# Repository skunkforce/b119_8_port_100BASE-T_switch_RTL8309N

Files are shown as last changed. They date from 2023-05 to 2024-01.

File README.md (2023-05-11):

# edgy_board number b119
This design is part of the [edgy board project](https://github.com/skunkforce/edgy_boards). It provides a cheap 8-port 100BASE-T switch.

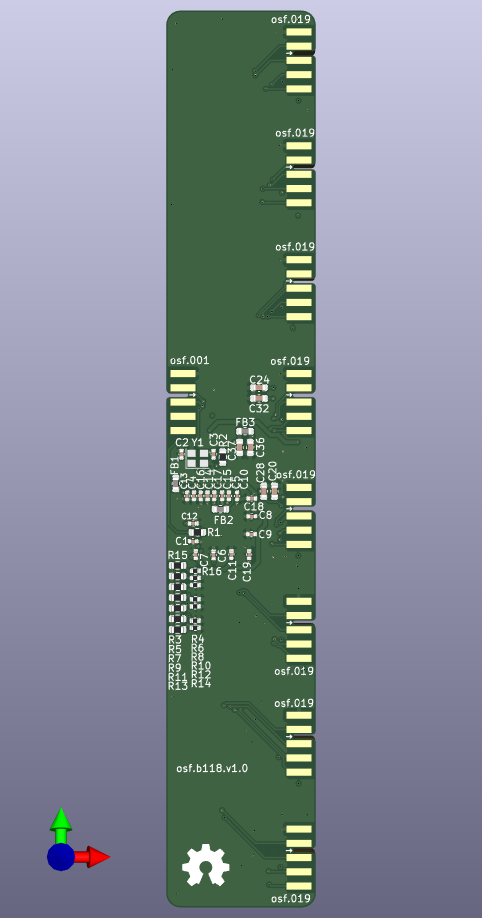
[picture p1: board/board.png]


# getting started
This repository uses submodules. After cloning use the command 

```$ git submodule update --init --recursive```

to pull the submodules before opening the project with kicad. 

# Tests
Tests can be found in [TESTS.md](TESTS.md)

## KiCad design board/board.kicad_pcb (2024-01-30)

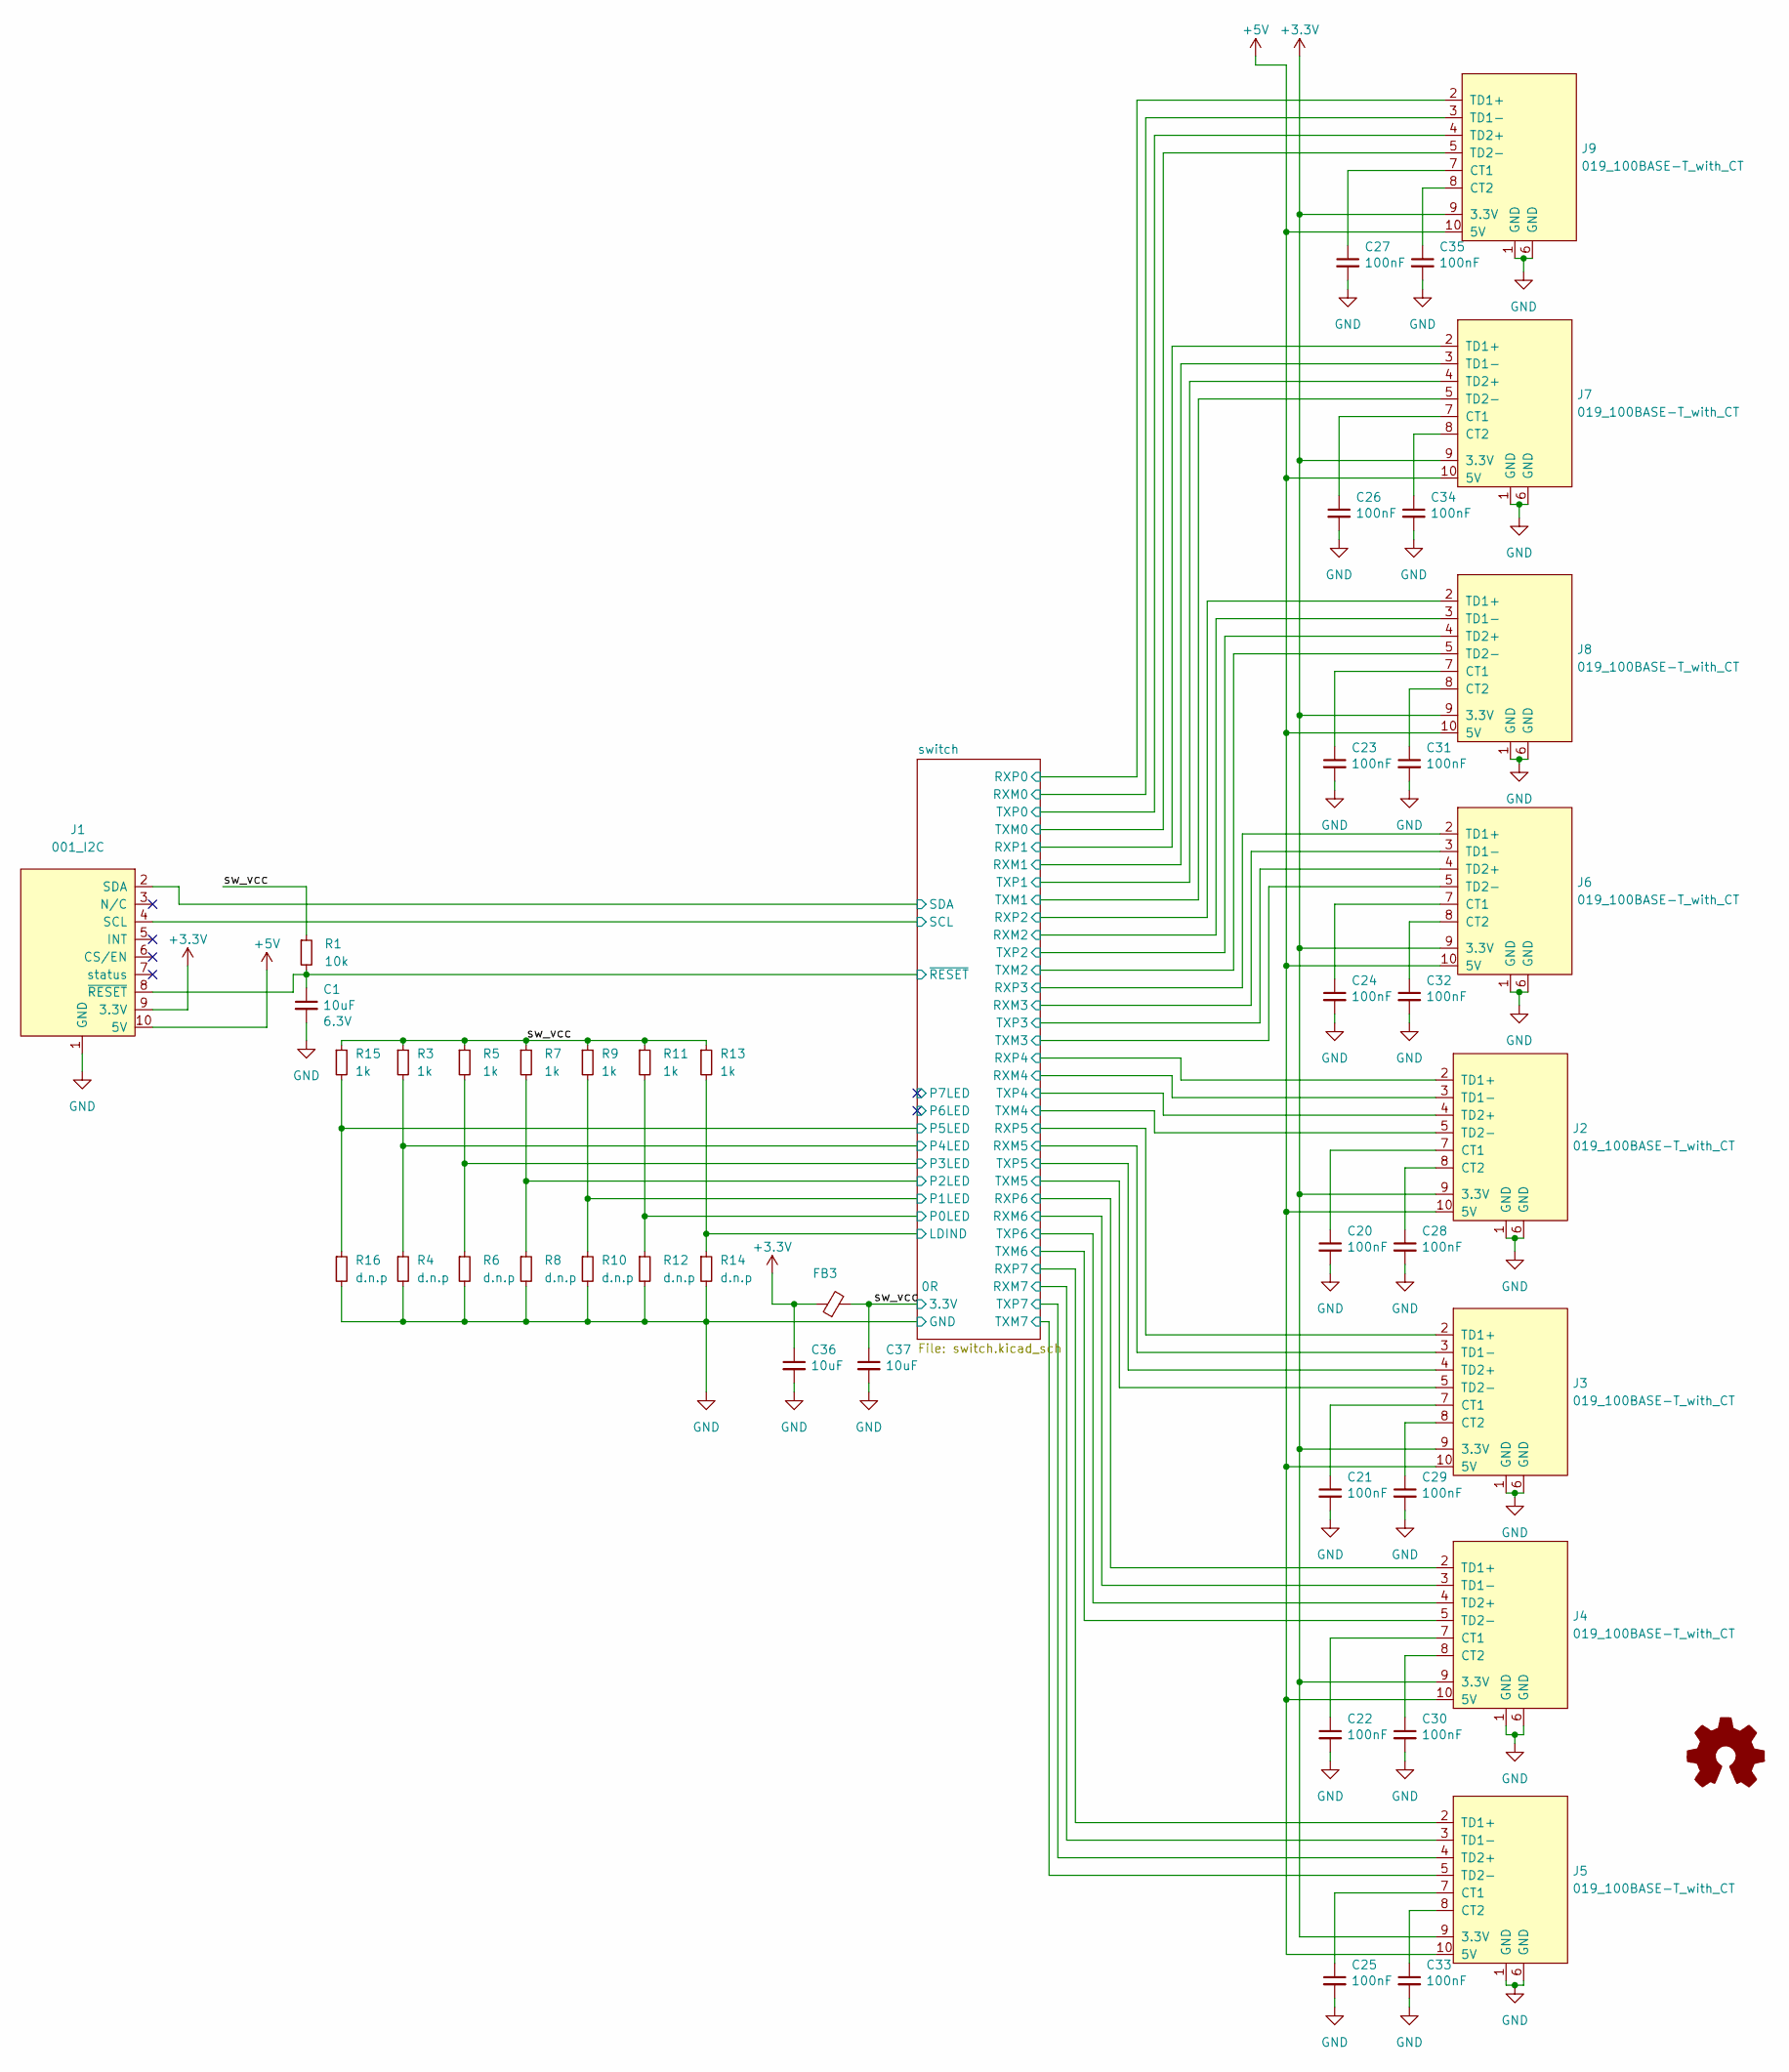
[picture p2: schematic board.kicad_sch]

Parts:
C1: 10uF; C_0402_1005Metric; Voltage 6.3V; MPN CL05A105MP5NNNC; Digi-Key_PN 1276-1448-1-ND
C20, C21, C22, C23, C24, C25, C26, C27, C28, C29, C30, C31, C32, C33, C34, C35: 100nF; C_0603_1608Metric; lcsc C14663
C36, C37: 10uF; C_0402_1005Metric; lcsc C15525
FB3: 0R; L_0603_1608Metric; MPN 74279228111; lcsc C21189
J1: 001_I2C; on_edge_2x05_device
J2, J3, J4, J5, J6, J7, J8, J9: 019_100BASE-T_with_CT; on_edge_2x05_host
LOGO1: Logo_Open_Hardware_Small; OSHW-Symbol_6.7x6mm_SilkScreen
R1: 10k; R_0402_1005Metric; lcsc C25744
R3, R5, R7, R9, R11, R13, R15: 1k; R_0402_1005Metric; lcsc C11702
R4, R6, R8, R10, R12, R14, R16: d.n.p; R_0402_1005Metric

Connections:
+3.3V: C36.1, FB3.1, J1.9 (3.3V), J2.9 (3.3V), J3.9 (3.3V), J4.9 (3.3V), J5.9 (3.3V), J6.9 (3.3V), J7.9 (3.3V), J8.9 (3.3V), J9.9 (3.3V)
+5V: J1.10 (5V), J2.10 (5V), J3.10 (5V), J4.10 (5V), J5.10 (5V), J6.10 (5V), J7.10 (5V), J8.10 (5V), J9.10 (5V)
/sw_vcc: C37.1, FB3.2, R1.1, R3.1, R5.1, R7.1, R9.1, R11.1, R13.1, R15.1; also elsewhere on the board
/switch/LDIND: R13.2, R14.1; also elsewhere on the board
/switch/P0LED: R11.2, R12.1; also elsewhere on the board
/switch/P1LED: R9.2, R10.1; also elsewhere on the board
/switch/P2LED: R7.2, R8.1; also elsewhere on the board
/switch/P3LED: R5.2, R6.1; also elsewhere on the board
/switch/P4LED: R3.2, R4.1; also elsewhere on the board
/switch/P5LED: R15.2, R16.1; also elsewhere on the board
/switch/RXM0: J9.3 (TD1-); also elsewhere on the board
/switch/RXM1: J7.3 (TD1-); also elsewhere on the board
/switch/RXM2: J8.3 (TD1-); also elsewhere on the board
/switch/RXM3: J6.3 (TD1-); also elsewhere on the board
/switch/RXM4: J2.3 (TD1-); also elsewhere on the board
/switch/RXM5: J3.3 (TD1-); also elsewhere on the board
/switch/RXM6: J4.3 (TD1-); also elsewhere on the board
/switch/RXM7: J5.3 (TD1-); also elsewhere on the board
/switch/RXP0: J9.2 (TD1+); also elsewhere on the board
/switch/RXP1: J7.2 (TD1+); also elsewhere on the board
/switch/RXP2: J8.2 (TD1+); also elsewhere on the board
/switch/RXP3: J6.2 (TD1+); also elsewhere on the board
/switch/RXP4: J2.2 (TD1+); also elsewhere on the board
/switch/RXP5: J3.2 (TD1+); also elsewhere on the board
/switch/RXP6: J4.2 (TD1+); also elsewhere on the board
/switch/RXP7: J5.2 (TD1+); also elsewhere on the board
/switch/SCL: J1.4 (SCL); also elsewhere on the board
/switch/SDA: J1.2 (SDA); also elsewhere on the board
/switch/TXM0: J9.5 (TD2-); also elsewhere on the board
/switch/TXM1: J7.5 (TD2-); also elsewhere on the board
/switch/TXM2: J8.5 (TD2-); also elsewhere on the board
/switch/TXM3: J6.5 (TD2-); also elsewhere on the board
/switch/TXM4: J2.5 (TD2-); also elsewhere on the board
/switch/TXM5: J3.5 (TD2-); also elsewhere on the board
/switch/TXM6: J4.5 (TD2-); also elsewhere on the board
/switch/TXM7: J5.5 (TD2-); also elsewhere on the board
/switch/TXP0: J9.4 (TD2+); also elsewhere on the board
/switch/TXP1: J7.4 (TD2+); also elsewhere on the board
/switch/TXP2: J8.4 (TD2+); also elsewhere on the board
/switch/TXP3: J6.4 (TD2+); also elsewhere on the board
/switch/TXP4: J2.4 (TD2+); also elsewhere on the board
/switch/TXP5: J3.4 (TD2+); also elsewhere on the board
/switch/TXP6: J4.4 (TD2+); also elsewhere on the board
/switch/TXP7: J5.4 (TD2+); also elsewhere on the board
/switch/~RESET: C1.1, J1.8 (~RESET), R1.2; also elsewhere on the board
GND: C1.2, C20.2, C21.2, C22.2, C23.2, C24.2, C25.2, C26.2, C27.2, C28.2, C29.2, C30.2, C31.2, C32.2, C33.2, C34.2, C35.2, C36.2, C37.2, J1.1 (GND), J2.1 (GND), J2.6 (GND), J3.1 (GND), J3.6 (GND), J4.1 (GND), J4.6 (GND), J5.1 (GND), J5.6 (GND), J6.1 (GND), J6.6 (GND), J7.1 (GND), J7.6 (GND), J8.1 (GND), J8.6 (GND), J9.1 (GND), J9.6 (GND), R4.2, R6.2, R8.2, R10.2, R12.2, R14.2, R16.2; also elsewhere on the board
unnamed: C20.1, J2.7 (CT1)
unnamed: C28.1, J2.8 (CT2)
unnamed: C21.1, J3.7 (CT1)
unnamed: C29.1, J3.8 (CT2)
unnamed: C22.1, J4.7 (CT1)
unnamed: C30.1, J4.8 (CT2)
unnamed: C25.1, J5.7 (CT1)
unnamed: C33.1, J5.8 (CT2)
unnamed: C24.1, J6.7 (CT1)
unnamed: C32.1, J6.8 (CT2)
unnamed: C26.1, J7.7 (CT1)
unnamed: C34.1, J7.8 (CT2)
unnamed: C23.1, J8.7 (CT1)
unnamed: C31.1, J8.8 (CT2)
unnamed: C27.1, J9.7 (CT1)
unnamed: C35.1, J9.8 (CT2)

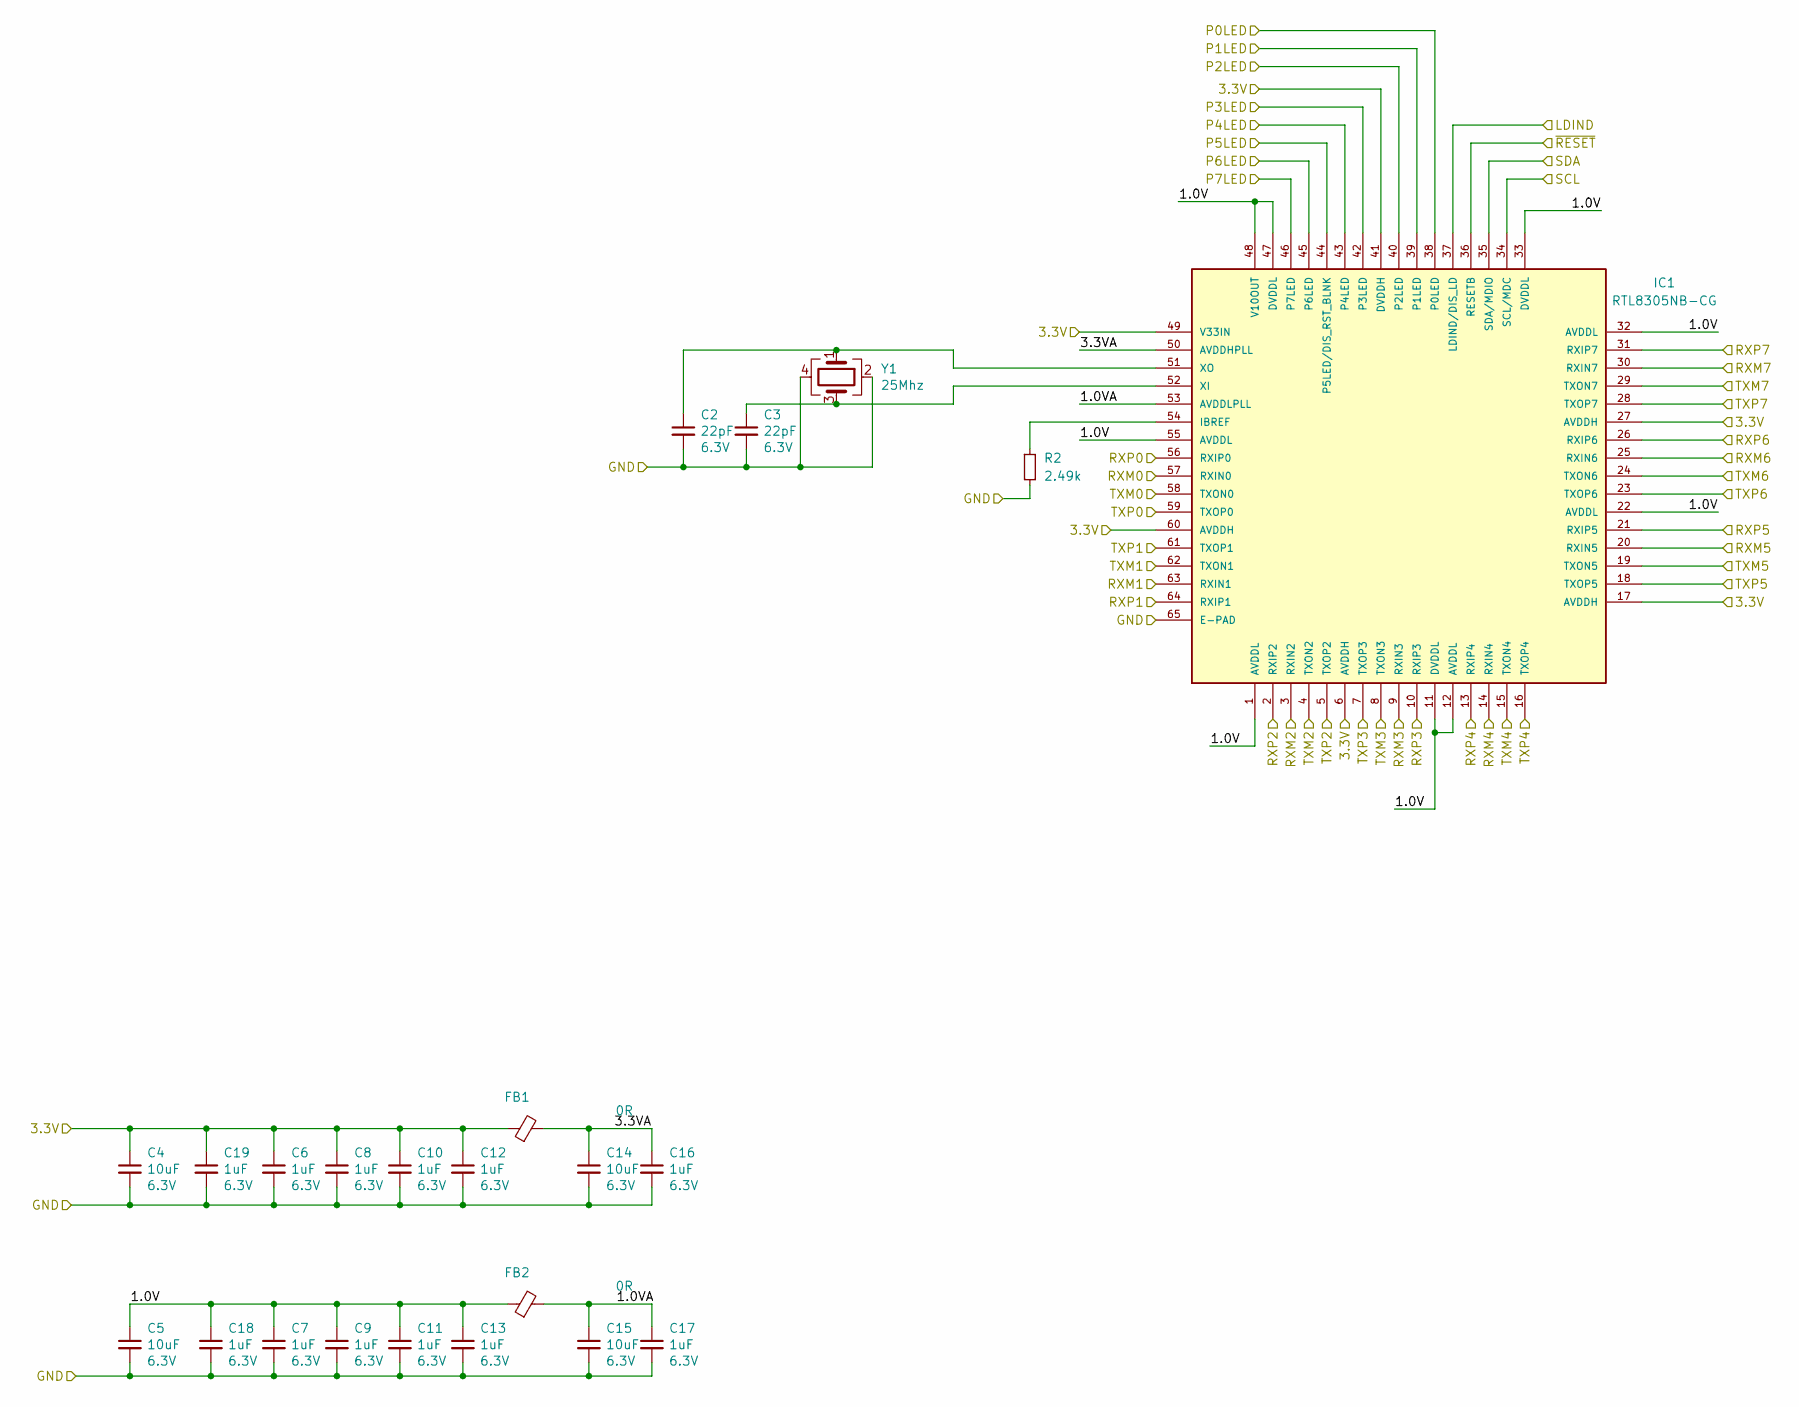
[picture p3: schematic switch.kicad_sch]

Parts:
C2, C3: 22pF; C_0402_1005Metric; Voltage 6.3V; Digi-Key_PN 1276-1665-1-ND
C4, C5, C14, C15: 10uF; C_0402_1005Metric; Voltage 6.3V; MPN CL05A105MP5NNNC; Digi-Key_PN 1276-1448-1-ND
C6, C7, C8, C9, C10, C11, C12, C13, C16, C17, C18, C19: 1uF; C_0402_1005Metric; Voltage 6.3V; MPN CL05A105MP5NNNC; Digi-Key_PN 1276-1448-1-ND
FB1, FB2: 0R; L_0603_1608Metric; MPN 74279228111; lcsc C21189
IC1: RTL8305NB-CG; QFN-64-1EP_9x9mm_P0.5mm_EP6x6mm; lcsc C52146
R2: 2.49k; R_0402_1005Metric; lcsc C25884
Y1: 25Mhz; Crystal_SMD_2520-4Pin_2.5x2.0mm; MPN ECS-250-18-36B-CKY-TR; lcsc C9006

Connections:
/sw_vcc: C4.1, C6.1, C8.1, C10.1, C12.1, C19.1, FB1.1, IC1.6 (AVDDH), IC1.17 (AVDDH), IC1.27 (AVDDH), IC1.41 (DVDDH), IC1.49 (V33IN), IC1.60 (AVDDH); also elsewhere on the board
/switch/1.0V: C5.1, C7.1, C9.1, C11.1, C13.1, C18.1, FB2.1, IC1.1 (AVDDL), IC1.11 (DVDDL), IC1.12 (AVDDL), IC1.22 (AVDDL), IC1.32 (AVDDL), IC1.33 (DVDDL), IC1.47 (DVDDL), IC1.48 (V10OUT), IC1.55 (AVDDL)
/switch/1.0VA: C15.1, C17.1, FB2.2, IC1.53 (AVDDLPLL)
/switch/3.3VA: C14.1, C16.1, FB1.2, IC1.50 (AVDDHPLL)
/switch/LDIND: IC1.37 (LDIND/DIS_LD); also elsewhere on the board
/switch/P0LED: IC1.38 (P0LED); also elsewhere on the board
/switch/P1LED: IC1.39 (P1LED); also elsewhere on the board
/switch/P2LED: IC1.40 (P2LED); also elsewhere on the board
/switch/P3LED: IC1.42 (P3LED); also elsewhere on the board
/switch/P4LED: IC1.43 (P4LED); also elsewhere on the board
/switch/P5LED: IC1.44 (P5LED/DIS_RST_BLNK); also elsewhere on the board
/switch/P6LED: IC1.45 (P6LED)
/switch/P7LED: IC1.46 (P7LED)
/switch/RXM0: IC1.57 (RXIN0); also elsewhere on the board
/switch/RXM1: IC1.63 (RXIN1); also elsewhere on the board
/switch/RXM2: IC1.3 (RXIN2); also elsewhere on the board
/switch/RXM3: IC1.9 (RXIN3); also elsewhere on the board
/switch/RXM4: IC1.14 (RXIN4); also elsewhere on the board
/switch/RXM5: IC1.20 (RXIN5); also elsewhere on the board
/switch/RXM6: IC1.25 (RXIN6); also elsewhere on the board
/switch/RXM7: IC1.30 (RXIN7); also elsewhere on the board
/switch/RXP0: IC1.56 (RXIP0); also elsewhere on the board
/switch/RXP1: IC1.64 (RXIP1); also elsewhere on the board
/switch/RXP2: IC1.2 (RXIP2); also elsewhere on the board
/switch/RXP3: IC1.10 (RXIP3); also elsewhere on the board
/switch/RXP4: IC1.13 (RXIP4); also elsewhere on the board
/switch/RXP5: IC1.21 (RXIP5); also elsewhere on the board
/switch/RXP6: IC1.26 (RXIP6); also elsewhere on the board
/switch/RXP7: IC1.31 (RXIP7); also elsewhere on the board
/switch/SCL: IC1.34 (SCL/MDC); also elsewhere on the board
/switch/SDA: IC1.35 (SDA/MDIO); also elsewhere on the board
/switch/TXM0: IC1.58 (TXON0); also elsewhere on the board
/switch/TXM1: IC1.62 (TXON1); also elsewhere on the board
/switch/TXM2: IC1.4 (TXON2); also elsewhere on the board
/switch/TXM3: IC1.8 (TXON3); also elsewhere on the board
/switch/TXM4: IC1.15 (TXON4); also elsewhere on the board
/switch/TXM5: IC1.19 (TXON5); also elsewhere on the board
/switch/TXM6: IC1.24 (TXON6); also elsewhere on the board
/switch/TXM7: IC1.29 (TXON7); also elsewhere on the board
/switch/TXP0: IC1.59 (TXOP0); also elsewhere on the board
/switch/TXP1: IC1.61 (TXOP1); also elsewhere on the board
/switch/TXP2: IC1.5 (TXOP2); also elsewhere on the board
/switch/TXP3: IC1.7 (TXOP3); also elsewhere on the board
/switch/TXP4: IC1.16 (TXOP4); also elsewhere on the board
/switch/TXP5: IC1.18 (TXOP5); also elsewhere on the board
/switch/TXP6: IC1.23 (TXOP6); also elsewhere on the board
/switch/TXP7: IC1.28 (TXOP7); also elsewhere on the board
/switch/~RESET: IC1.36 (RESETB); also elsewhere on the board
GND: C2.2, C3.2, C4.2, C5.2, C6.2, C7.2, C8.2, C9.2, C10.2, C11.2, C12.2, C13.2, C14.2, C15.2, C16.2, C17.2, C18.2, C19.2, IC1.65 (E-PAD), R2.2, Y1.2, Y1.4; also elsewhere on the board
unnamed: IC1.54 (IBREF), R2.1
unnamed: C3.1, IC1.52 (XI), Y1.3
unnamed: C2.1, IC1.51 (XO), Y1.1

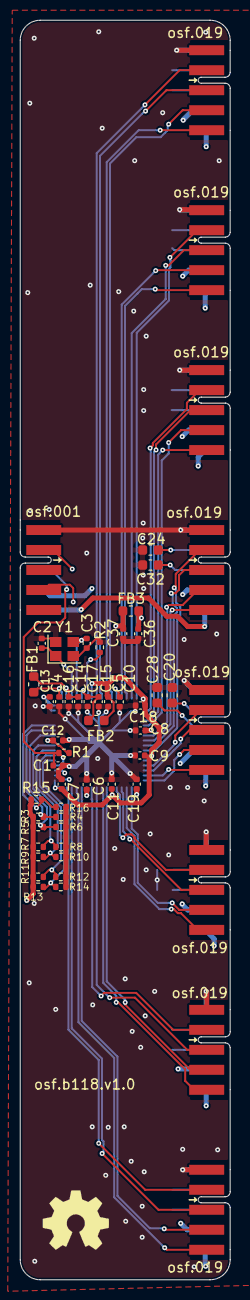
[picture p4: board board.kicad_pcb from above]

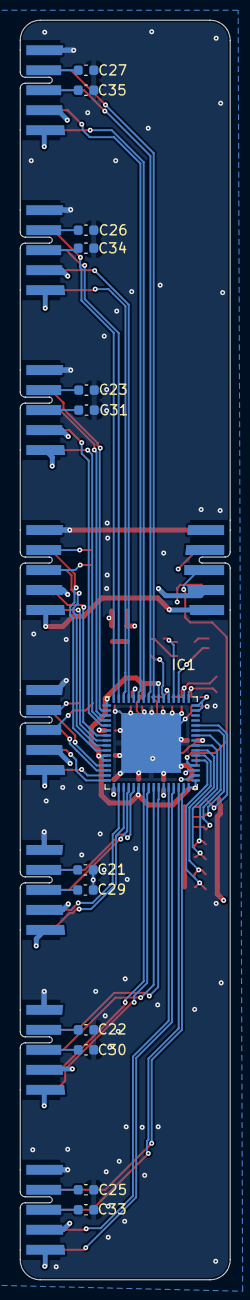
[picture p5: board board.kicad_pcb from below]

Board: 4 copper layers, 21.0 x 126.0 mm, 68 parts (13 on the bottom side), 68 nets.

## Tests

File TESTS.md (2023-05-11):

# communication test
## setup
Connected usb -> b051 -> b103 -> b119 for power and b119 -> b004 -> ethernet 2x and tested communication between them.
## results
fast communication was possible.

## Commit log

2023-03-29 added decoupling components
    [board.kicad_pcb, board.kicad_sch, implementation.kicad_sch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]
2023-03-30 added N filter for input voltage
    [board.kicad_pcb, board.kicad_sch]
2024-01-30 added lcsc numbers and updated I2C connector
    [board.kicad_pcb, board.kicad_sch, switch.kicad_sch]
